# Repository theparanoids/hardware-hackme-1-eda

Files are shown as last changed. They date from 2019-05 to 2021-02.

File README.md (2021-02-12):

# ARCHIVED 

# Paranoids Hardware Hackme 1 -- EDA Files
> PCB design files for hackme designed by the Paranoids security team.



The Paranoids security team has designed this PCB to serve as a platform for building CTF (capture-the-flag) challenges.

## Table of Contents

- [Background](#background)
- [Install](#install)
- [Usage](#usage)
- [Contribute](#contribute)
- [License](#license)
- [Shoutouts](#shoutouts)

## Background

PCBs and CTF challenges are fun. Paranoids wanted some fun too. This board was designed by the Paranoids team to be a platform for "hardware" or "embedded systems" capture-the-flag challenges. In a capture-the-flag challenge, a system is designed with deliberate security weaknesses, and the goal for the person playing the challenge is to find and exploit these weaknesses. This board contains a "victim" STM32F4 microcontroller and XC2C32A CPLD. It also has a secondary microcontroller that can act as a debugger for the "victim" microcontroller. This secondary microcontroller can run the open-source [Black Magic Probe](https://github.com/blacksphere/blackmagic) firmware. These components are all conveniently integrated into one board -- no need to connect multiple smaller boards together with a bunch of wires.

## Install

This project is designed in [KiCad](http://kicad-pcb.org/). To edit the files, install a KiCad version at least as recent as 5.0.0-rc2-dev-319-g0ded476.

## Usage

To make changes to the schematic or board layout, open the main `paranoids-hackme-1.pro` project file in KiCad. Schematics for revisions that have gone out to manufacturing are checked in as PDFs for convenience. Gerber files for revisions that have gone out to manufacturing are also checked in for convenience.

This board has been designed with 6 mil trace width, 6 mil minimum spacing, 12 mil minimum drill, and 24 mil minimum via diameter. This is compatible with many PCB manufacturers including [OSHPark](https://oshpark.com/) and [PCBWay](https://www.pcbway.com/).

## Contribute

Please refer to [the contributing.md file](Contributing.md) for information about how to get involved. We welcome issues and questions. Pull Requests may be accepted. However, because manufacturing physical hardware costs money and the Paranoids does not regularly manufacture new batches of PCBs, proposed changes should be thoroughly discussed and agreed upon before submitting a pull request.

## Maintainers
Robert Ou: robert.ou@verizonmedia.com

## License
This project is licensed under the terms of the [MIT](LICENSE-MIT) open source license. Please refer to [LICENSE](LICENSE) for the full terms.

## Shoutouts
* Andrew Zonenberg for his [KiCad libraries](https://github.com/azonenberg/kicad-libraries)
* The [Black Magic Probe](https://github.com/blacksphere/blackmagic) developers for their open-source firmware

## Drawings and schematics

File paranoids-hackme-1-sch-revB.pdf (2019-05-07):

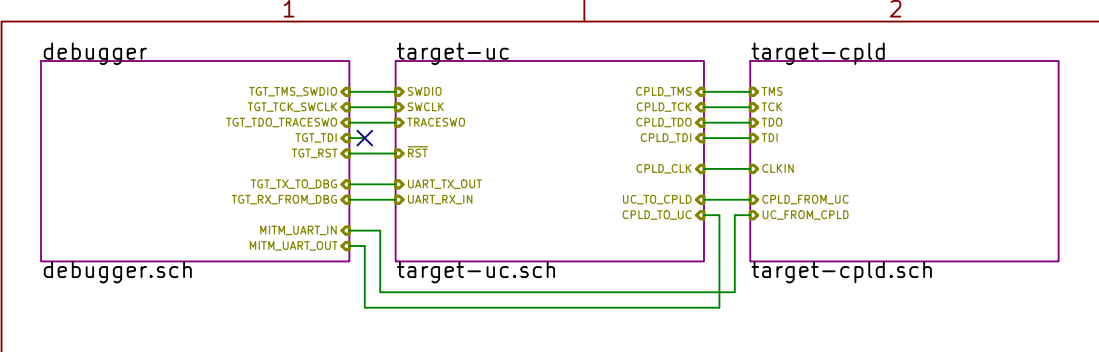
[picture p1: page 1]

File: paranoids-hackme-1.sch Sheet: / Oath Inc

Id: 1/4 Title: Paranoids Hackme 1

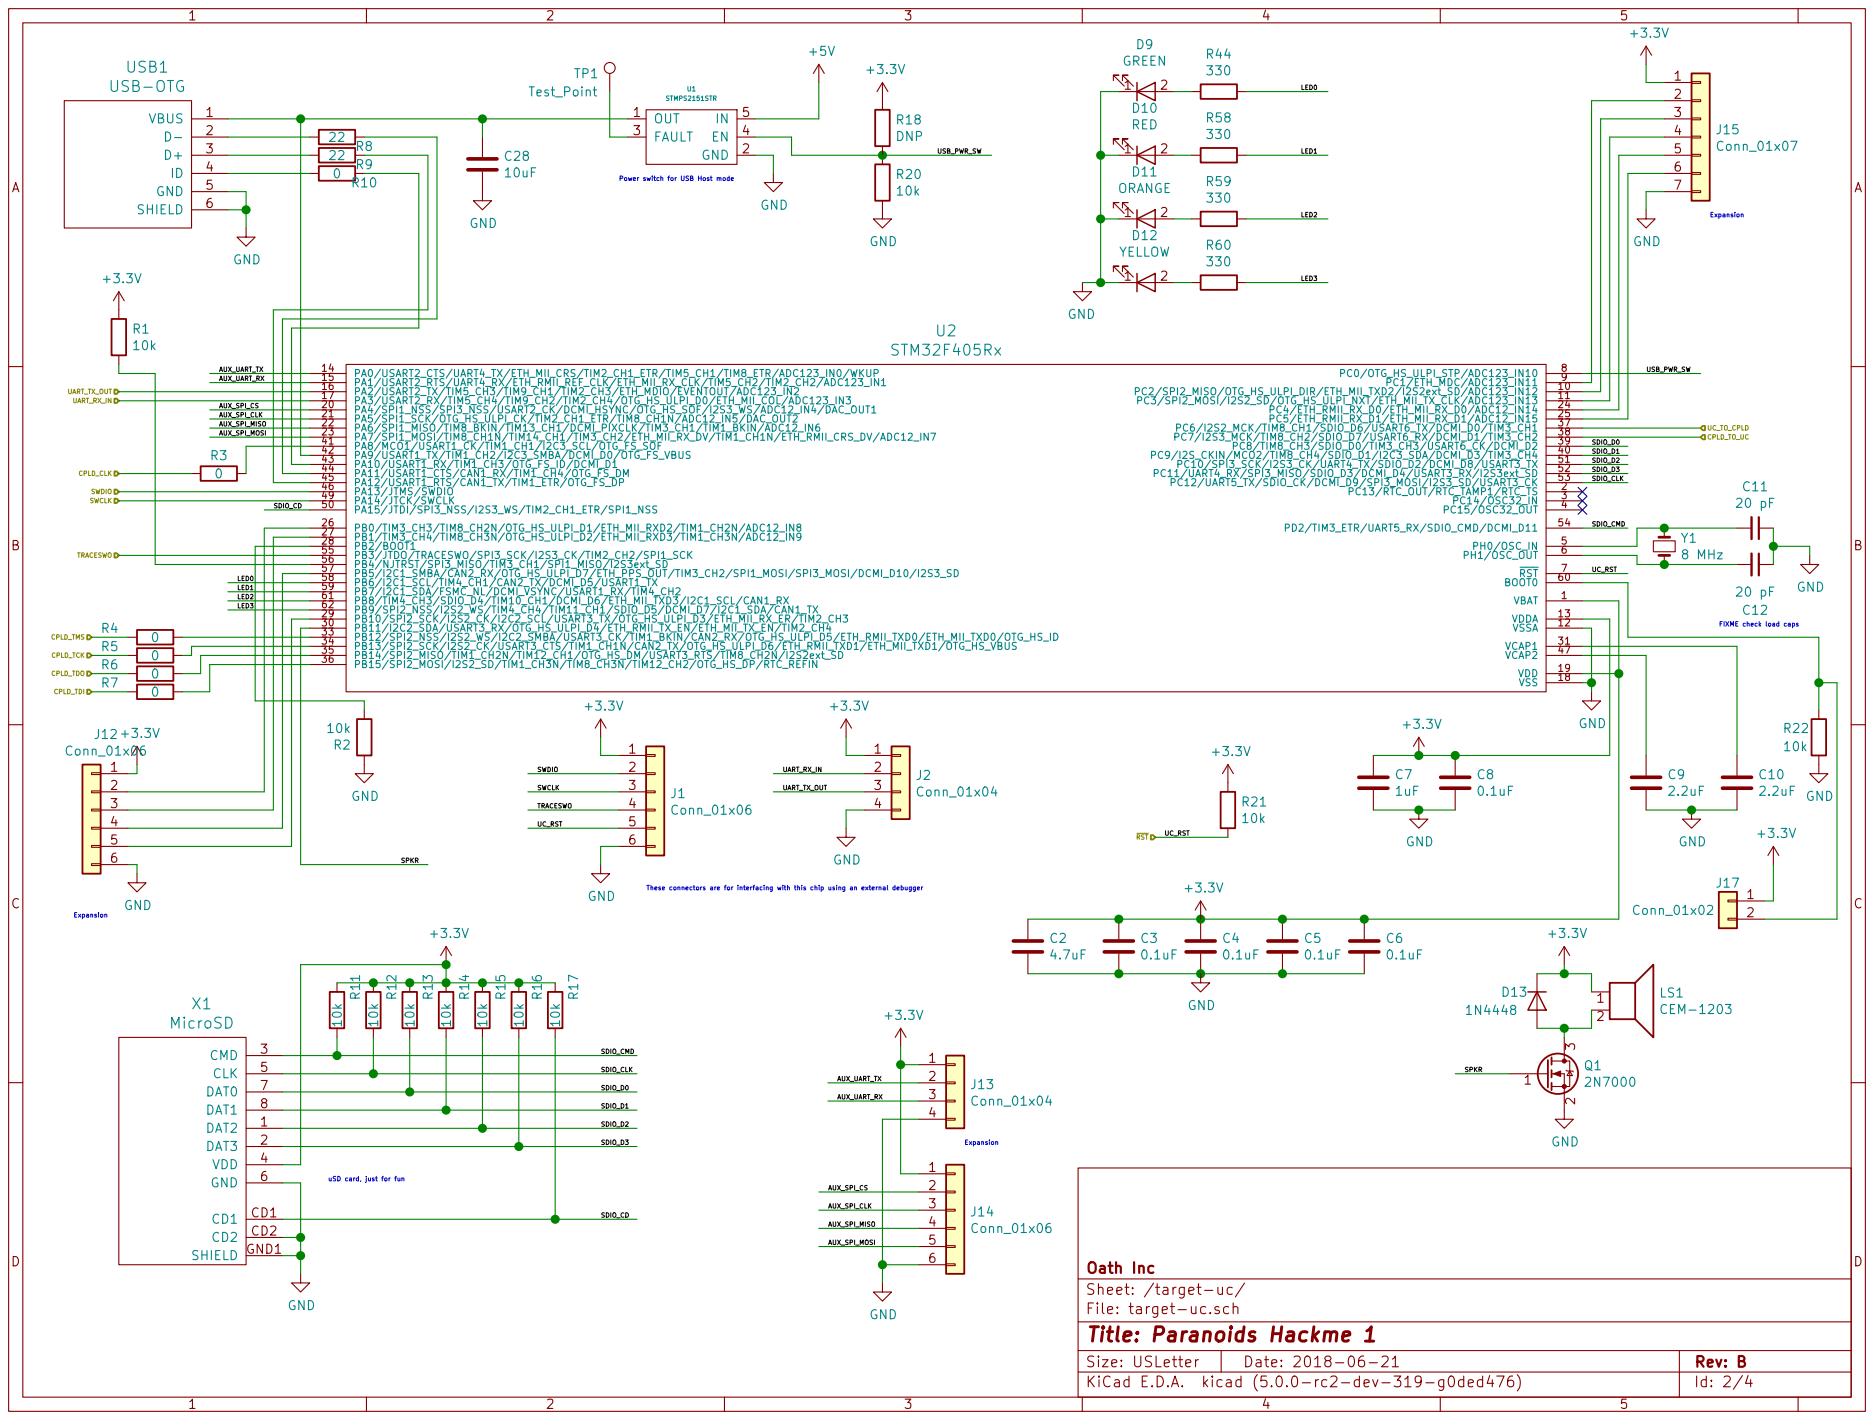
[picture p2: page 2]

+5V GND
10uF GND GND
Power switch for USB Host mode 1

AUX_SPI_CS

FIXME check load caps C9

These connectors are for interfacing with this chip using an external debugger uSD card, just for fun

Sheet: /target-uc/ Oath Inc

File: target-uc.sch
Id: 2/4 Title: Paranoids Hackme 1

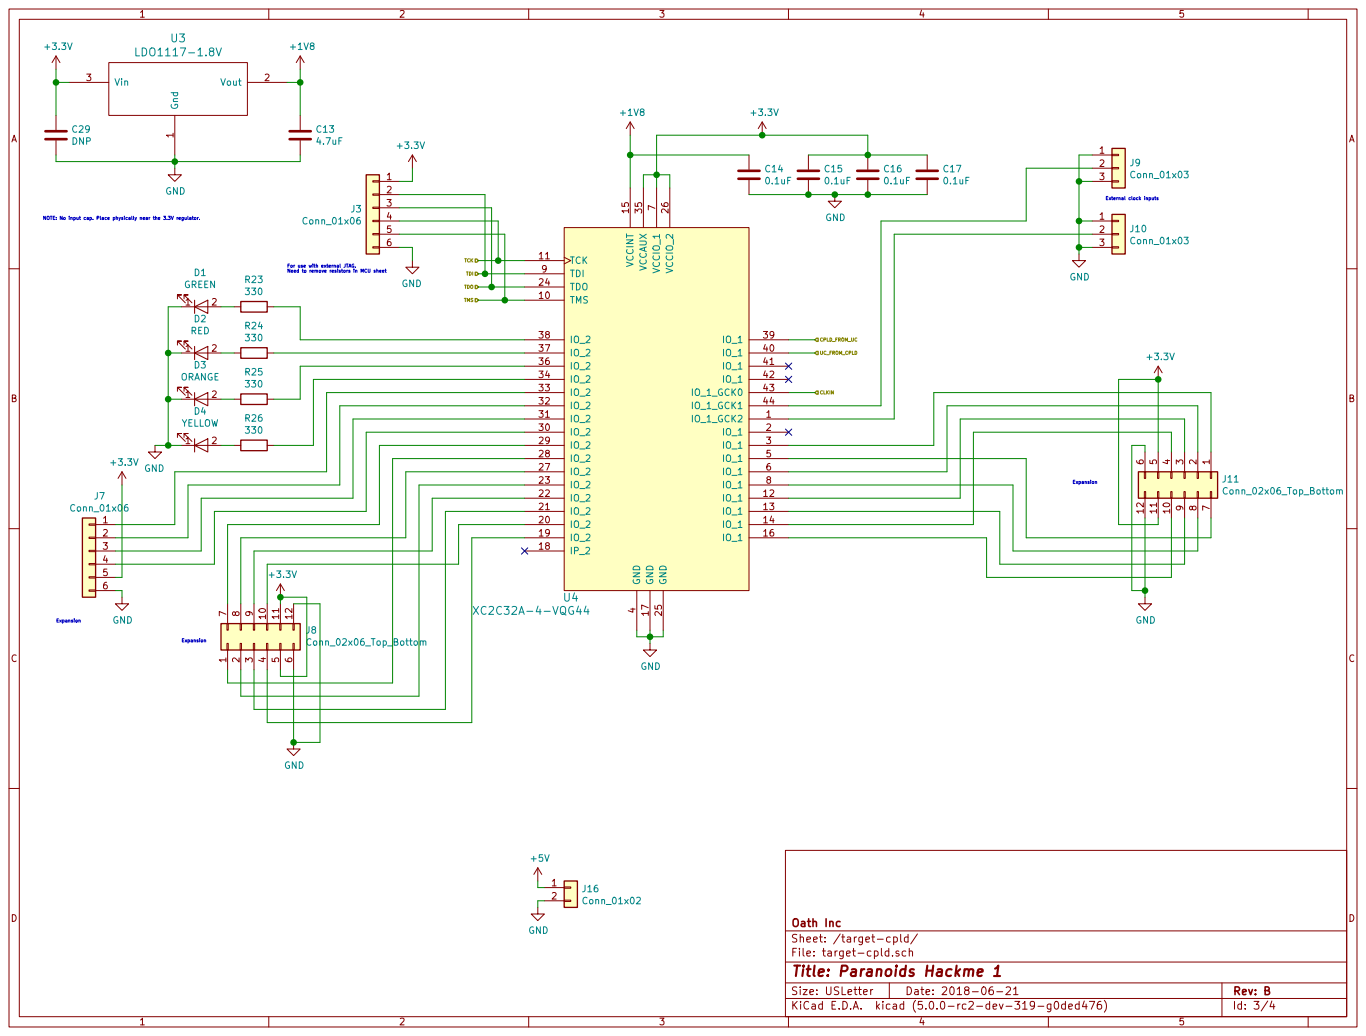
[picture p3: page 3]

Sheet: /target-cpld/ Oath Inc Gnd

External clock inputs C29 DNP

File: target-cpld.sch
Id: 3/4 Title: Paranoids Hackme 1

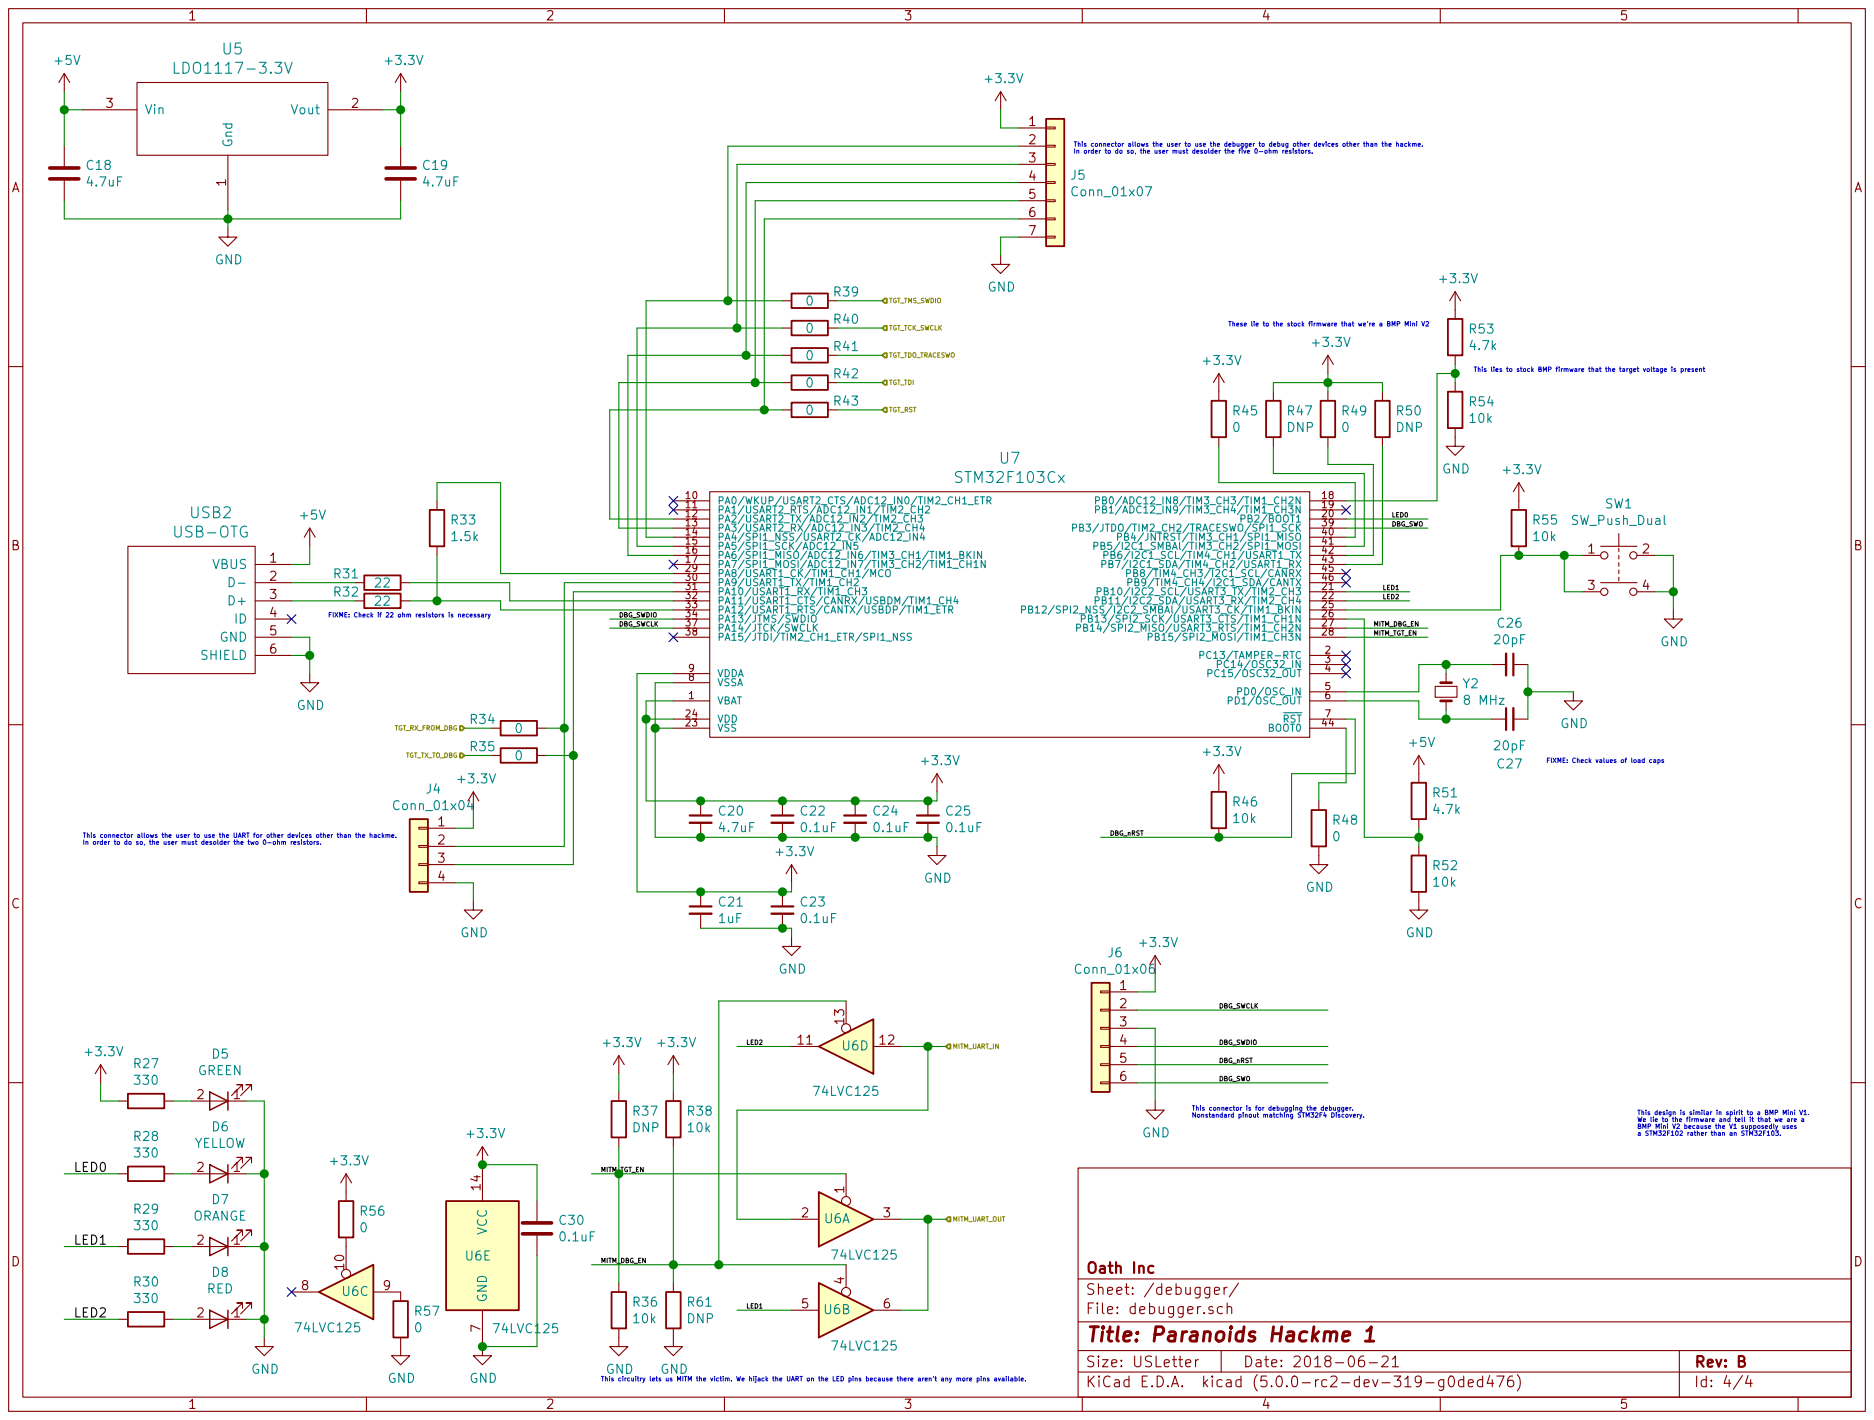
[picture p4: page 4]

This connector allows the user to use the debugger to debug other devices other than the hackme.
In order to do so, the user must desolder the five 0-ohm resistors.

These lie to the stock firmware that were a BMP Mini V2

FIXME: Check if 22 ohm resistors is necessary This connector allows the user to use the UART for other devices other than the hackme.

Sheet: /debugger/ Oath Inc

File: debugger.sch
Id: 4/4 Title: Paranoids Hackme 1

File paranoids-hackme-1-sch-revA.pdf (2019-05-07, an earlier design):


File: paranoids-hackme-1.sch Sheet: / Oath Inc

Id: 1/4 Title: Paranoids Hackme 1

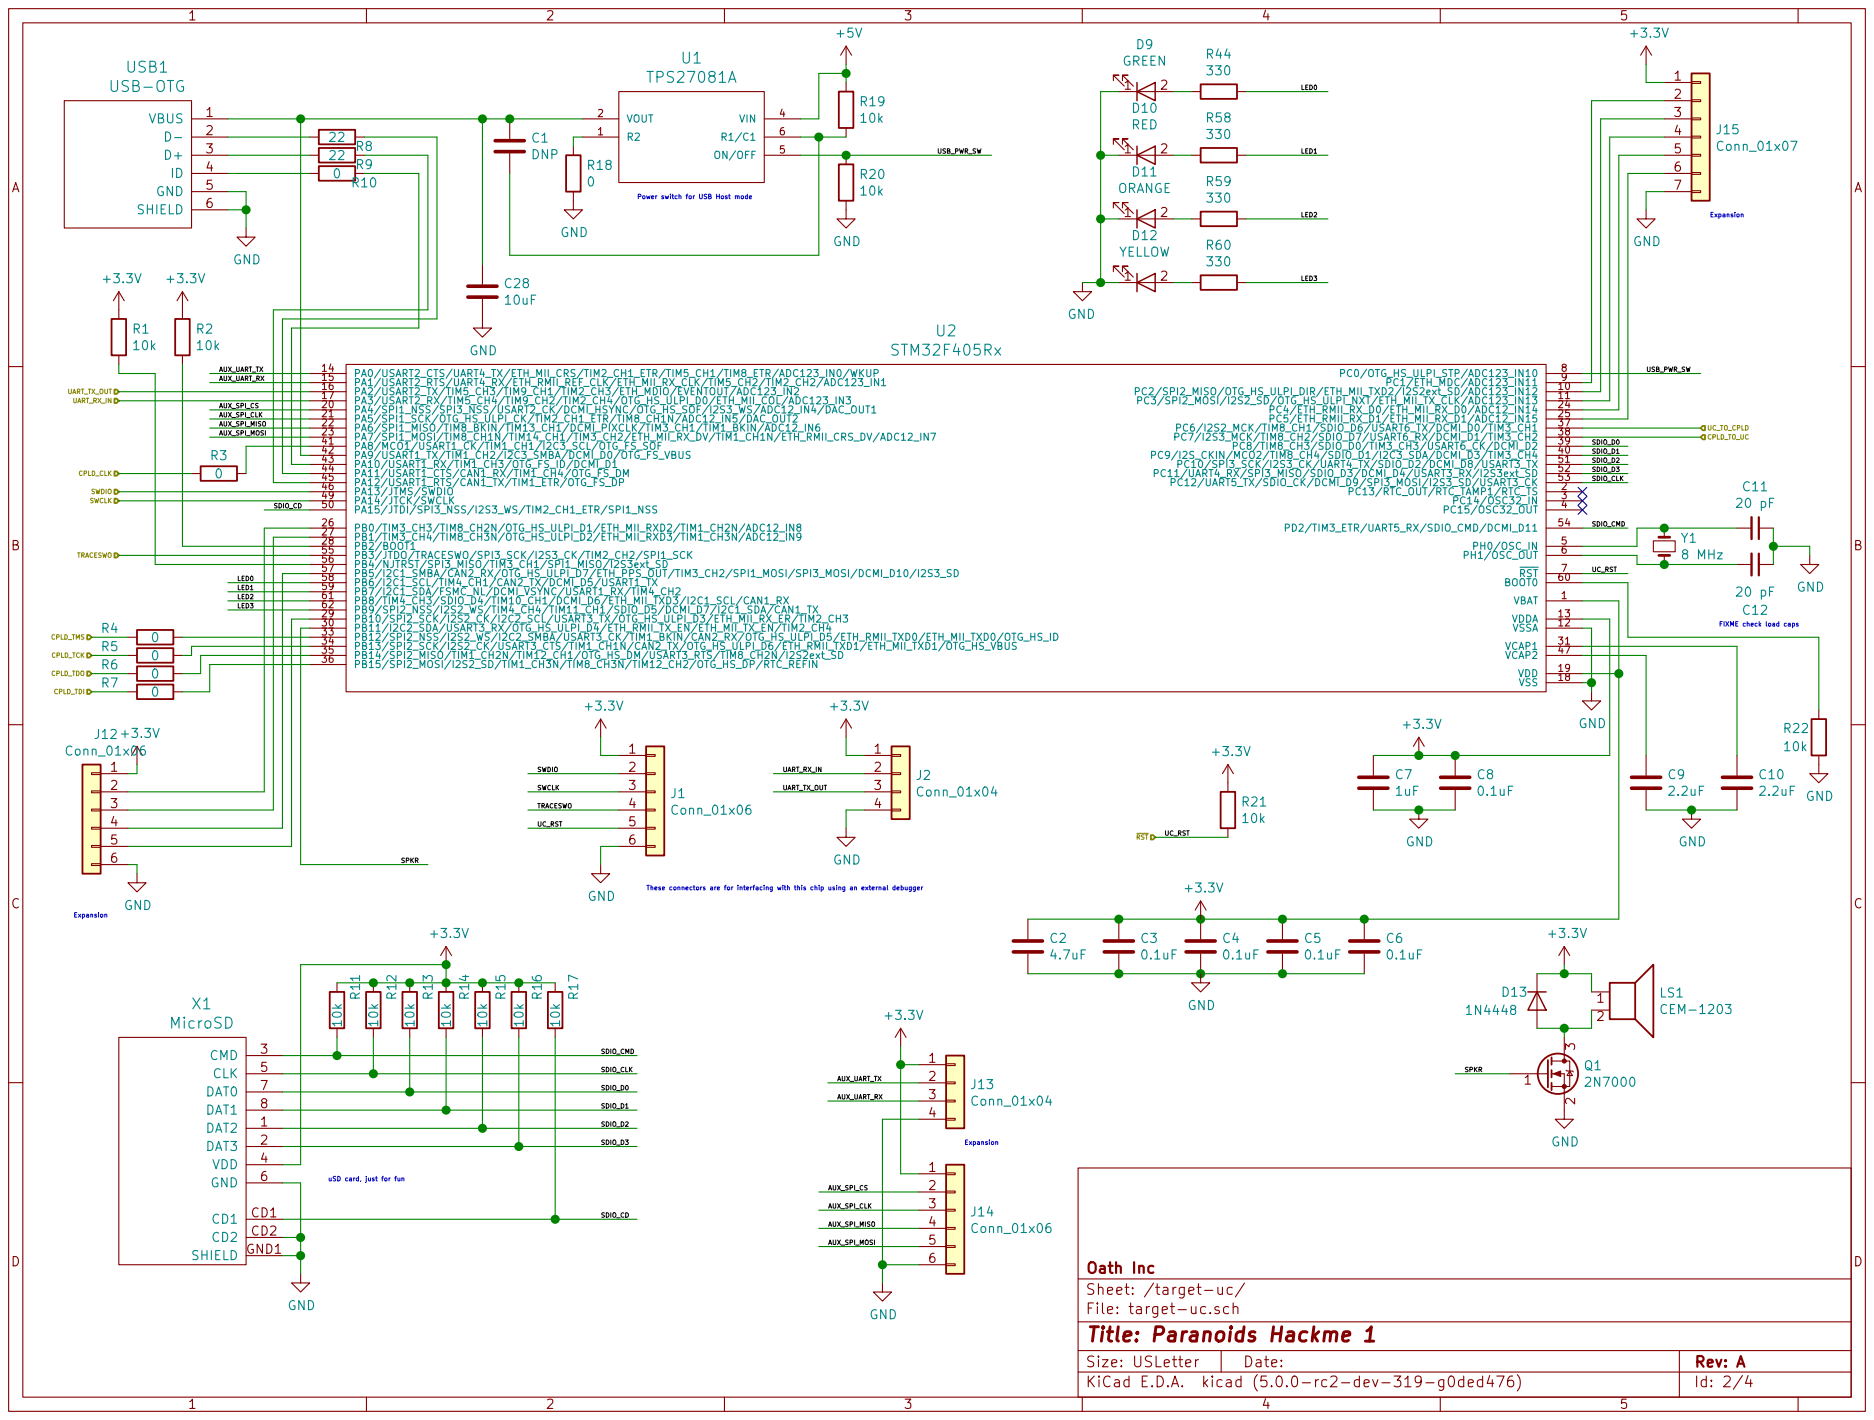
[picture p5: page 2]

Power switch for USB Host mode 1

AUX_SPI_CS

FIXME check load caps C9

These connectors are for interfacing with this chip using an external debugger uSD card, just for fun

Sheet: /target-uc/ Oath Inc

File: target-uc.sch
Id: 2/4 Title: Paranoids Hackme 1

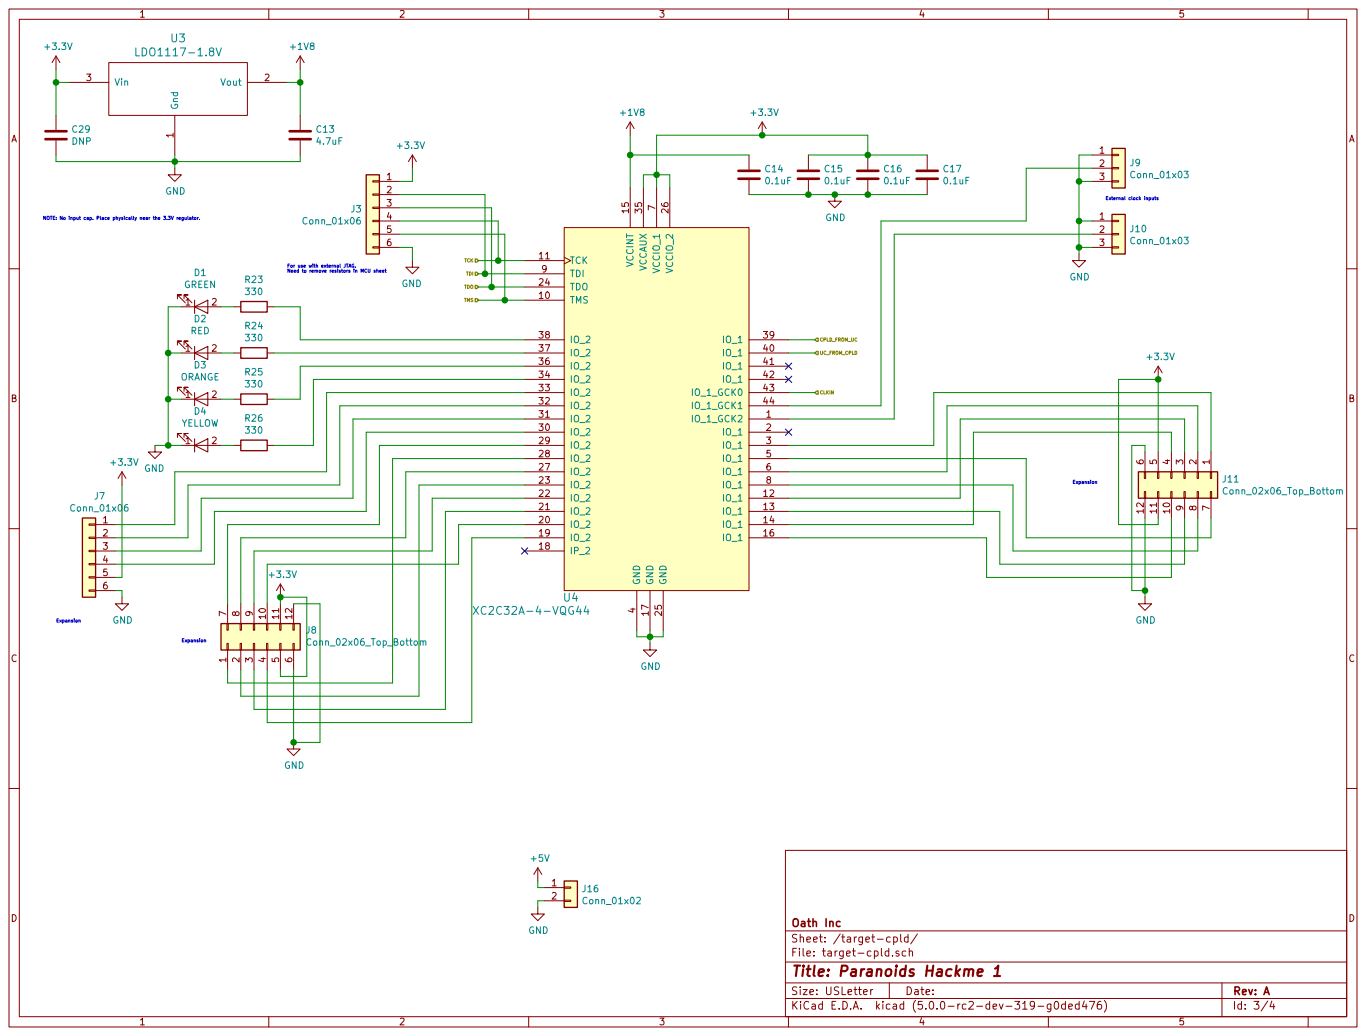
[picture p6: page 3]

Sheet: /target-cpld/ Oath Inc Gnd

External clock inputs C29 DNP

File: target-cpld.sch
Id: 3/4 Title: Paranoids Hackme 1

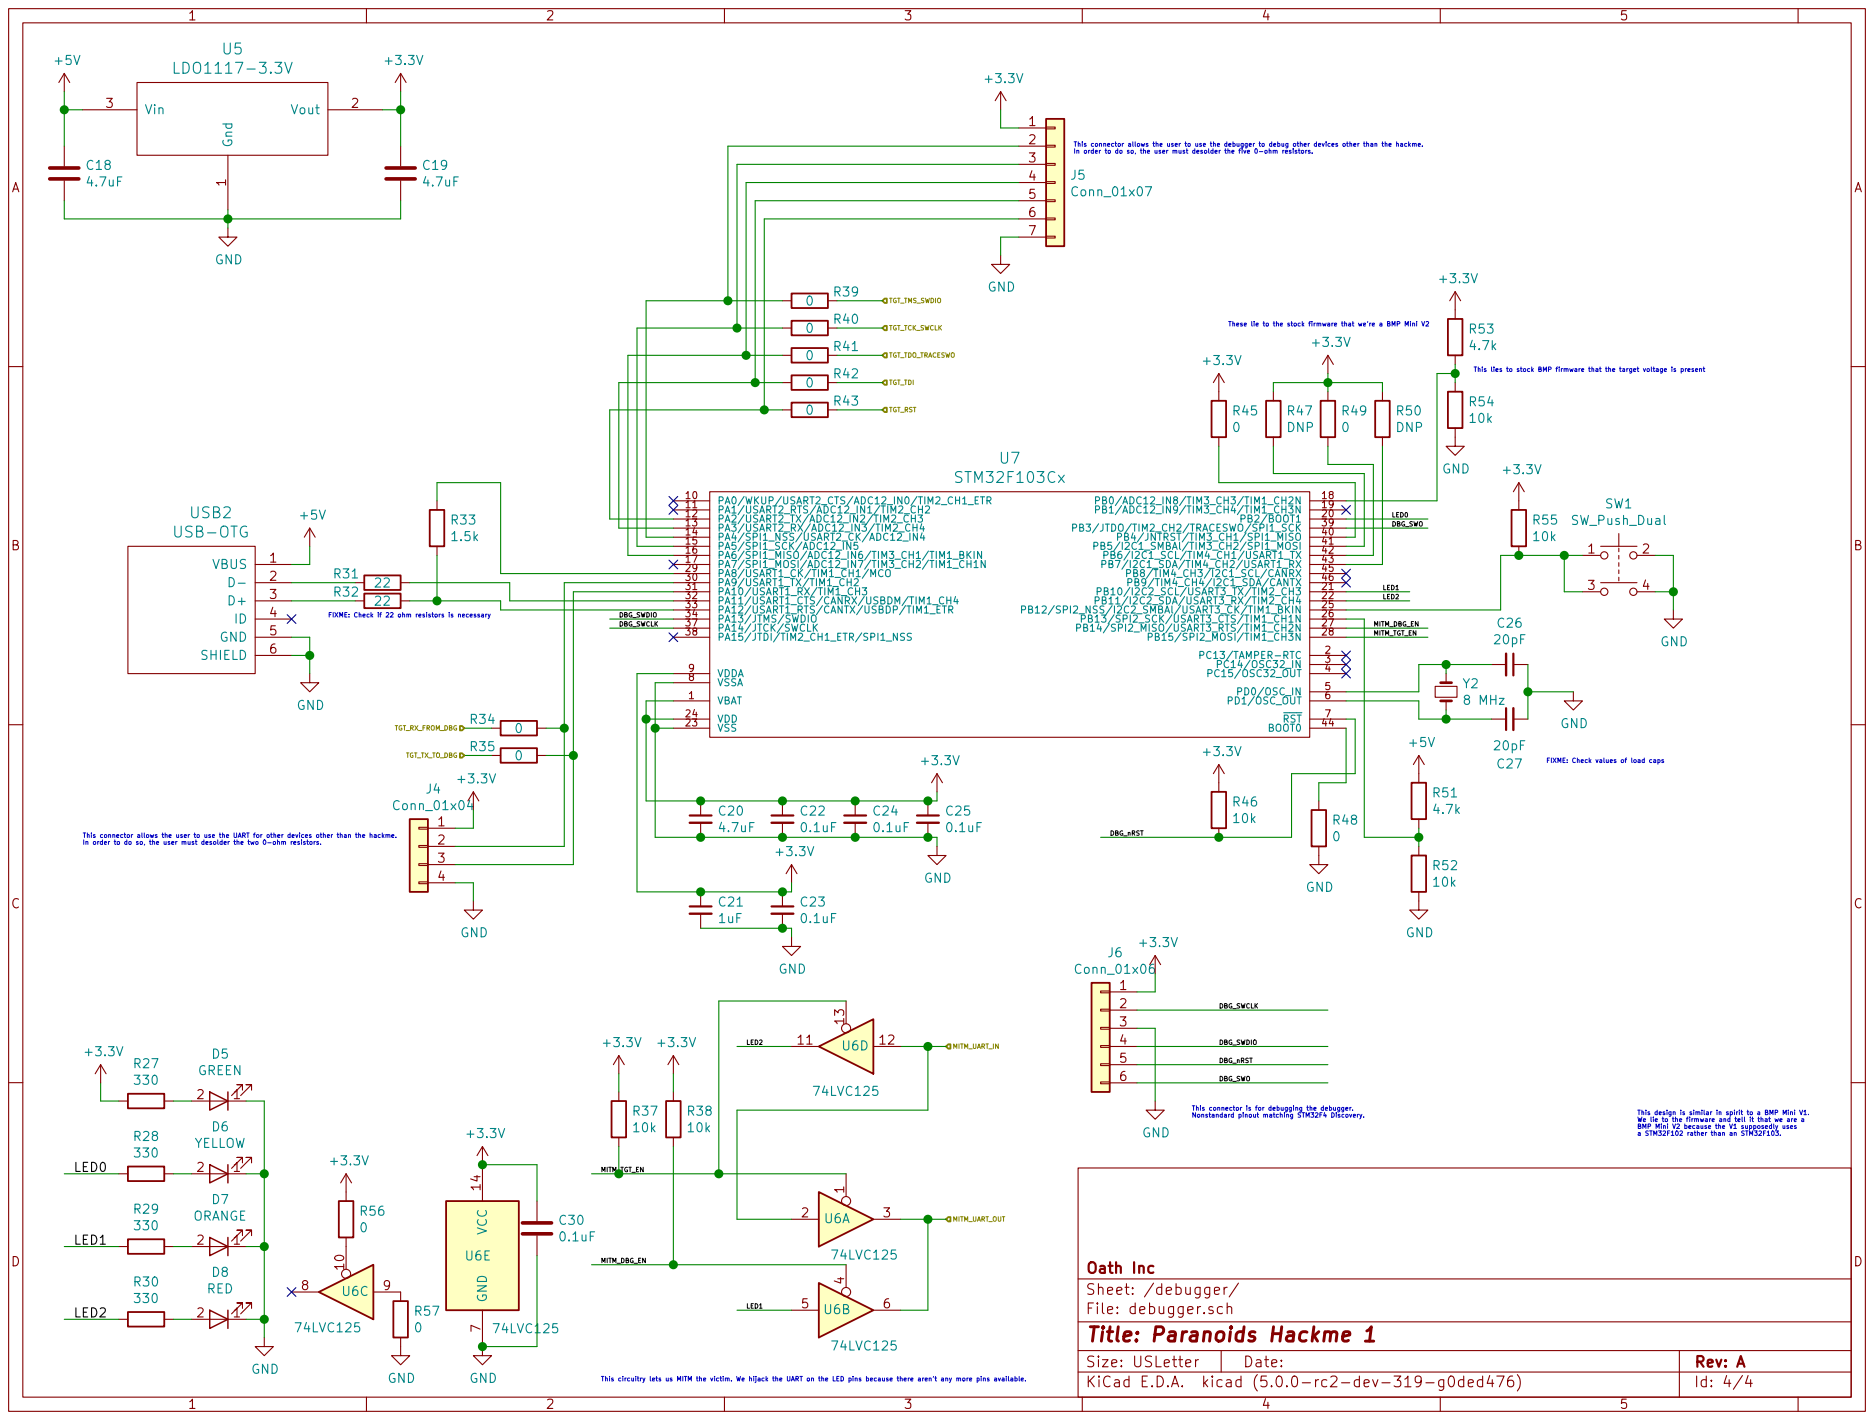
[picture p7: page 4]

This connector allows the user to use the debugger to debug other devices other than the hackme.
In order to do so, the user must desolder the five 0-ohm resistors.

These lie to the stock firmware that were a BMP Mini V2

FIXME: Check if 22 ohm resistors is necessary This connector allows the user to use the UART for other devices other than the hackme.

Sheet: /debugger/ Oath Inc

File: debugger.sch
Id: 4/4 Title: Paranoids Hackme 1

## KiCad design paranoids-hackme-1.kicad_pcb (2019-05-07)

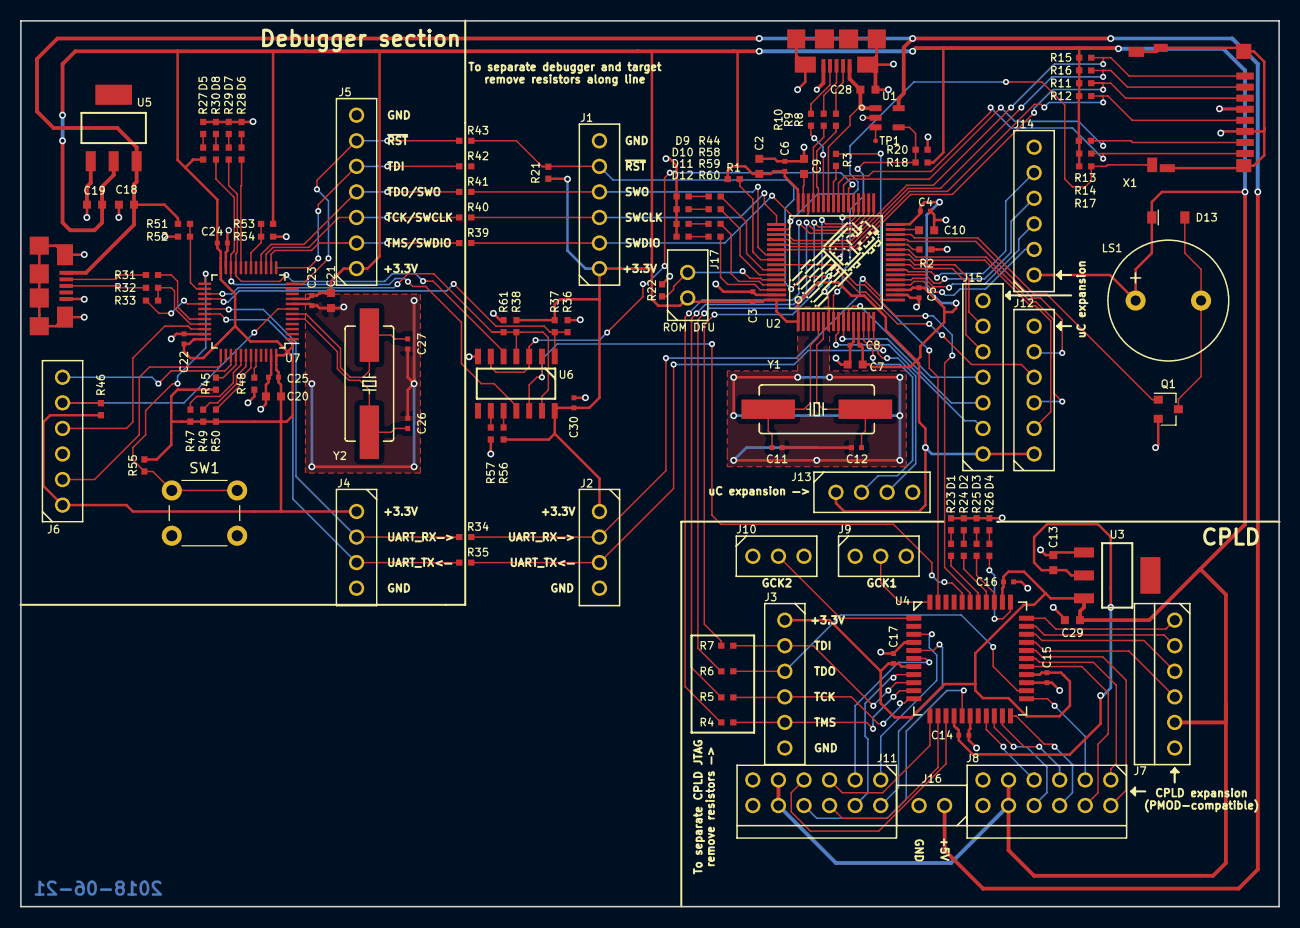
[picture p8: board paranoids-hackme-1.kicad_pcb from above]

Board: 2 copper layers, 125.0 x 88.0 mm, 136 parts (0 on the bottom side), 138 nets.

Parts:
C2, C13, C18, C19, C20: 4.7uF; EIA_0603_CAP_NOSILK
C3, C4, C5, C6, C8, C14, C15, C16, C17, C22, C23, C24, C25, C30: 0.1uF; EIA_0402_CAP_NOSILK
C7, C21: 1uF; EIA_0603_CAP_NOSILK
C9, C10: 2.2uF; EIA_0603_CAP_NOSILK
C11, C12: 20 pF; EIA_0402_CAP_NOSILK
C26, C27: 20pF; EIA_0402_CAP_NOSILK
C28: 10uF; EIA_0603_CAP_NOSILK
C29: DNP; EIA_0603_CAP_NOSILK
D1, D5, D9: GREEN; EIA_0402_LED
D2, D8, D10: RED; EIA_0402_LED
D3, D7, D11: ORANGE; EIA_0402_LED
D4, D6, D12: YELLOW; EIA_0402_LED
D13: 1N4448; SOD123
J1, J3, J6, J12, J14: Conn_01x06; CONN_HEADER_2.54MM_1x6
J2, J4, J13: Conn_01x04; CONN_HEADER_2.54MM_1x4
J5, J15: Conn_01x07; CONN_HEADER_2.54MM_1x7
J7: Conn_01x06; CONN_HEADER_2.54MM_1x6_RA
J8, J11: Conn_02x06_Top_Bottom; CONN_HEADER_2.54MM_2x6_RA_PMOD_HOST
J9, J10: Conn_01x03; CONN_HEADER_2.54MM_1x3
J16, J17: Conn_01x02; CONN_HEADER_2.54MM_1x2
LS1: CEM-1203; BUZZER_CEM-1203
Q1: 2N7000; SOT-23
R1, R2, R11, R12, R13, R14, R15, R16, R17, R20, R21, R22, R36, R38, R46, R52, R54, R55: 10k; EIA_0402_RES_NOSILK
R3, R4, R5, R6, R7, R10, R34, R35, R39, R40, R41, R42, R43, R45, R48, R49, R56, R57: 0; EIA_0402_RES_NOSILK
R8, R9, R31, R32: 22; EIA_0402_RES_NOSILK
R18, R37, R47, R50, R61: DNP; EIA_0402_RES_NOSILK
R23, R24, R25, R26, R27, R28, R29, R30, R44, R58, R59, R60: 330; EIA_0402_RES_NOSILK
R33: 1.5k; EIA_0402_RES_NOSILK
R51, R53: 4.7k; EIA_0402_RES_NOSILK
Ref**: Val**; NYAN-1CM
SW1: SW_Push_Dual; SW_PUSH_6mm
TP1: Test_Point; TESTPOINT_SMT_0.5MM
U1: STMPS2151STR; STO23-5L
U2: STM32F405Rx; QFP64
U3: LDO1117-1.8V; SOT223-4
U4: XC2C32A-4-VQG44; QFP_44_0.8MM
U5: LDO1117-3.3V; SOT223-4
U6: 74LVC125; SOIC_14_3.9MM
U7: STM32F103Cx; LQFP-48_7x7mm_Pitch0.5mm
USB1, USB2: USB-OTG; USB-MICRO-AB
X1: MicroSD; uSD-114-00841-68
Y1, Y2: 8 MHz; HC49UP

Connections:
+1V8: C13.1, C14.1, U3.2, U4.15
+3V3: C2.1, C3.1, C4.1, C5.1, C6.1, C7.1, C8.1, C15.1, C16.1, C17.1, C19.1, C20.1, C21.1, C22.1, C23.1, C24.1, C25.1, C29.1, C30.1, D13.1, J1.1, J2.1, J3.1, J4.1, J5.1, J6.1, J7.5, J8.5, J8.11, J11.5, J11.11, J12.1, J13.1, J14.1, J15.1, J17.1, LS1.1, R1.1, R11.1, R12.1, R13.1, R14.1, R15.1, R16.1, R17.1, R18.1, R21.1, R27.2, R37.1, R38.1, R45.1, R46.1, R47.1, R49.1, R50.1, R53.1, R55.1, R56.1, U2.1, U2.13, U2.19, U2.32, U2.48, U2.64, U3.3, U4.7, U4.26, U4.35, U5.2, U6.14, U7.1, U7.9, U7.24, U7.36, U7.48, X1.4
+5V: C18.1, J16.1, R51.1, U1.5, U5.3, USB2.1
/debugger/DBG_SWCLK: J6.2, U7.37
/debugger/DBG_SWDIO: J6.4, U7.34
/debugger/DBG_SWO: J6.6, U7.39
/debugger/DBG_nRST: J6.5, R46.2, U7.7
/debugger/LED0: R28.2, U7.20
/debugger/LED1: R29.2, U6.5, U7.21
/debugger/LED2: R30.2, U6.11, U7.22
/debugger/MITM_DBG_EN: R38.2, R61.1, U6.4, U6.13, U7.27
/debugger/MITM_TGT_EN: R36.1, R37.2, U6.1, U7.28
/debugger/MITM_UART_IN: U4.40, U6.2, U6.12
/debugger/TGT_RST: J1.5, R21.2, R43.1, U2.7
/debugger/TGT_RX_FROM_DBG: J2.2, R34.2, U2.17
/debugger/TGT_TDO_TRACESWO: J1.4, R41.1, U2.55
/debugger/TGT_TX_TO_DBG: J2.3, R35.2, U2.16
/target-cpld/CLKIN: R3.2, U4.43
/target-cpld/CPLD_FROM_UC: U2.37, U4.39
/target-uc/AUX_SPI_CLK: J14.3, U2.21
/target-uc/AUX_SPI_CS: J14.2, U2.20
/target-uc/AUX_SPI_MISO: J14.4, U2.22
/target-uc/AUX_SPI_MOSI: J14.5, U2.23
/target-uc/AUX_UART_RX: J13.3, U2.15
/target-uc/AUX_UART_TX: J13.2, U2.14
/target-uc/CPLD_TCK: J3.4, R5.2, U4.11
/target-uc/CPLD_TDI: J3.2, R7.2, U4.9
/target-uc/CPLD_TDO: J3.3, R6.2, U4.24
/target-uc/CPLD_TMS: J3.5, R4.2, U4.10
/target-uc/CPLD_TO_UC: U2.38, U6.3, U6.6
/target-uc/LED0: R44.2, U2.58
/target-uc/LED1: R58.2, U2.59
/target-uc/LED2: R59.2, U2.61
/target-uc/LED3: R60.2, U2.62
/target-uc/SDIO_CD: R17.2, U2.50, X1.CD1
/target-uc/SDIO_CLK: R12.2, U2.53, X1.5
/target-uc/SDIO_CMD: R11.2, U2.54, X1.3
/target-uc/SDIO_D0: R13.2, U2.39, X1.7
/target-uc/SDIO_D1: R14.2, U2.40, X1.8
/target-uc/SDIO_D2: R15.2, U2.51, X1.1
/target-uc/SDIO_D3: R16.2, U2.52, X1.2
/target-uc/SPKR: Q1.1, U2.30
/target-uc/SWCLK: J1.3, R40.1, U2.49
/target-uc/SWDIO: J1.2, R39.1, U2.46
/target-uc/USB_PWR_SW: R18.2, R20.1, U1.4, U2.8
GND: C2.2, C3.2, C4.2, C5.2, C6.2, C7.2, C8.2, C9.2, C10.2, C11.1, C12.1, C13.2, C14.2, C15.2, C16.2, C17.2, C18.2, C19.2, C20.2, C21.2, C22.2, C23.2, C24.2, C25.2, C26.1, C27.2, C28.2, C29.2, C30.2, D1.1, D2.1, D3.1, D4.1, D5.1, D6.1, D7.1, D8.1, D9.1, D10.1, D11.1, D12.1, J1.6, J2.4, J3.6, J4.4, J5.7, J6.3, J7.6, J8.6, J8.12, J9.1, J9.3, J10.1, J10.3, J11.6, J11.12, J12.6, J13.4, J14.6, J15.7, J16.2, Q1.2, R2.1, R20.2, R22.2, R36.2, R48.2, R52.2, R54.2, R57.2, R61.2, SW1.2, U1.2, U2.12, U2.18, U2.63, U3.1, U4.4, U4.17, U4.25, U5.1, U6.7, U7.8, U7.23, U7.35, U7.47, USB1.5, USB1.6, USB1.7, USB1.8, USB1.9, USB1.10, USB1.11, USB2.5, USB2.6, USB2.7, USB2.8, USB2.9, USB2.10, USB2.11, X1.6, X1.CD2, X1.GND1, X1.GND2, X1.GND3, X1.GND4
unnamed: C9.1, U2.47
unnamed: C10.1, U2.31
unnamed: C11.2, U2.5, Y1.1
unnamed: C12.2, U2.6, Y1.2
unnamed: C26.2, U7.5, Y2.1
unnamed: C27.1, U7.6, Y2.2
unnamed: C28.1, U1.1, U2.42, USB1.1
unnamed: D1.2, R23.1
unnamed: D2.2, R24.1
unnamed: D3.2, R25.1
unnamed: D4.2, R26.1
unnamed: D5.2, R27.1
unnamed: D6.2, R28.1
unnamed: D7.2, R29.1
unnamed: D8.2, R30.1
unnamed: D9.2, R44.1
unnamed: D10.2, R58.1
unnamed: D11.2, R59.1
unnamed: D12.2, R60.1
unnamed: D13.2, LS1.2, Q1.3
unnamed: J4.2, R34.1, U7.30
unnamed: J4.3, R35.1, U7.31
unnamed: J5.2, R39.2, U7.14
unnamed: J5.3, R40.2, U7.15
unnamed: J5.4, R41.2, U7.16
unnamed: J5.5, R42.2, U7.13
unnamed: J5.6, R43.2, U7.12
unnamed: J7.1, U4.33
unnamed: J7.2, U4.32
unnamed: J7.3, U4.31
unnamed: J7.4, U4.30
unnamed: J8.1, U4.28
unnamed: J8.2, U4.23
unnamed: J8.3, U4.21
unnamed: J8.4, U4.19
unnamed: J8.7, U4.29
unnamed: J8.8, U4.27
unnamed: J8.9, U4.22
unnamed: J8.10, U4.20
unnamed: J9.2, U4.44
unnamed: J10.2, U4.1
unnamed: J11.1, U4.3
unnamed: J11.2, U4.6
unnamed: J11.3, U4.12
unnamed: J11.4, U4.14
unnamed: J11.7, U4.5
unnamed: J11.8, U4.8
unnamed: J11.9, U4.13
unnamed: J11.10, U4.16
unnamed: J12.2, U2.26
unnamed: J12.3, U2.27
unnamed: J12.4, U2.57
unnamed: J12.5, U2.29
unnamed: J15.2, U2.9
unnamed: J15.3, U2.10
unnamed: J15.4, U2.11
unnamed: J15.5, U2.24
unnamed: J15.6, U2.25
unnamed: J17.2, R22.1, U2.60
unnamed: R1.2, U2.56
unnamed: R2.2, U2.28
unnamed: R3.1, U2.41
unnamed: R4.1, U2.33
unnamed: R5.1, U2.34
unnamed: R6.1, U2.35
unnamed: R7.1, U2.36
unnamed: R8.1, U2.44
unnamed: R8.2, USB1.2
unnamed: R9.1, U2.45
unnamed: R9.2, USB1.3
unnamed: R10.1, U2.43
unnamed: R10.2, USB1.4
unnamed: R23.2, U4.38
unnamed: R24.2, U4.37
unnamed: R25.2, U4.36
unnamed: R26.2, U4.34
unnamed: R31.1, U7.32
unnamed: R31.2, USB2.2
unnamed: R32.1, R33.2, U7.33
unnamed: R32.2, USB2.3
unnamed: R33.1, U7.29
unnamed: R45.2, U7.40
unnamed: R47.2, U7.41
unnamed: R48.1, U7.44
unnamed: R49.2, U7.42
unnamed: R50.2, U7.43
unnamed: R51.2, R52.1, U7.26
unnamed: R53.2, R54.1, U7.18
unnamed: R55.2, SW1.1, U7.25
unnamed: R56.2, U6.10
unnamed: R57.1, U6.9
unnamed: TP1.1, U1.3
